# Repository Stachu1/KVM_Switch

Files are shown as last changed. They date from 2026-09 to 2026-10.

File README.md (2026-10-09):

# KVM Switch

A two-computer HDMI + USB KVM switch designed in KiCad.

This is a personal project with the goal of learning more about digital high-speed PCB design: controlled-impedance differential pairs, length matching, layer stackup and keeping signal integrity in check on HDMI and USB lines.

## PCB

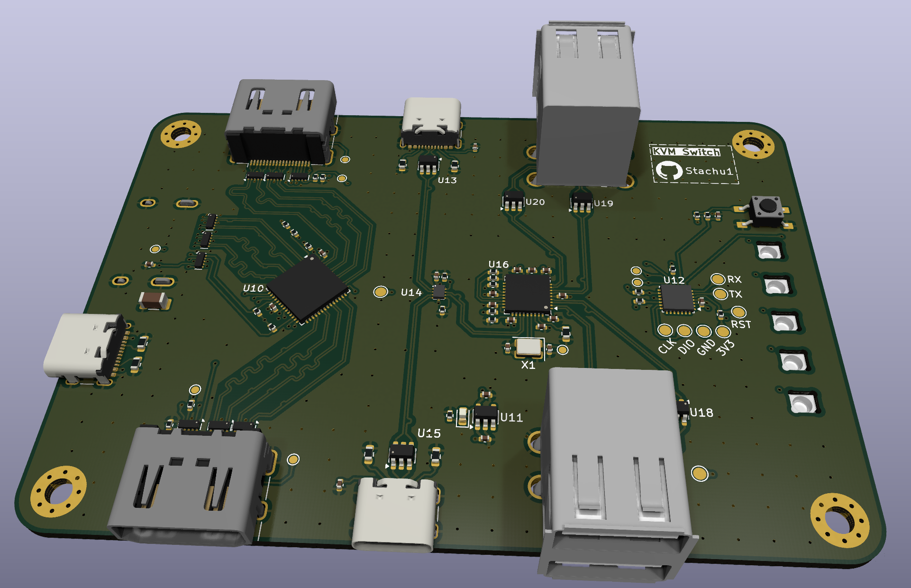
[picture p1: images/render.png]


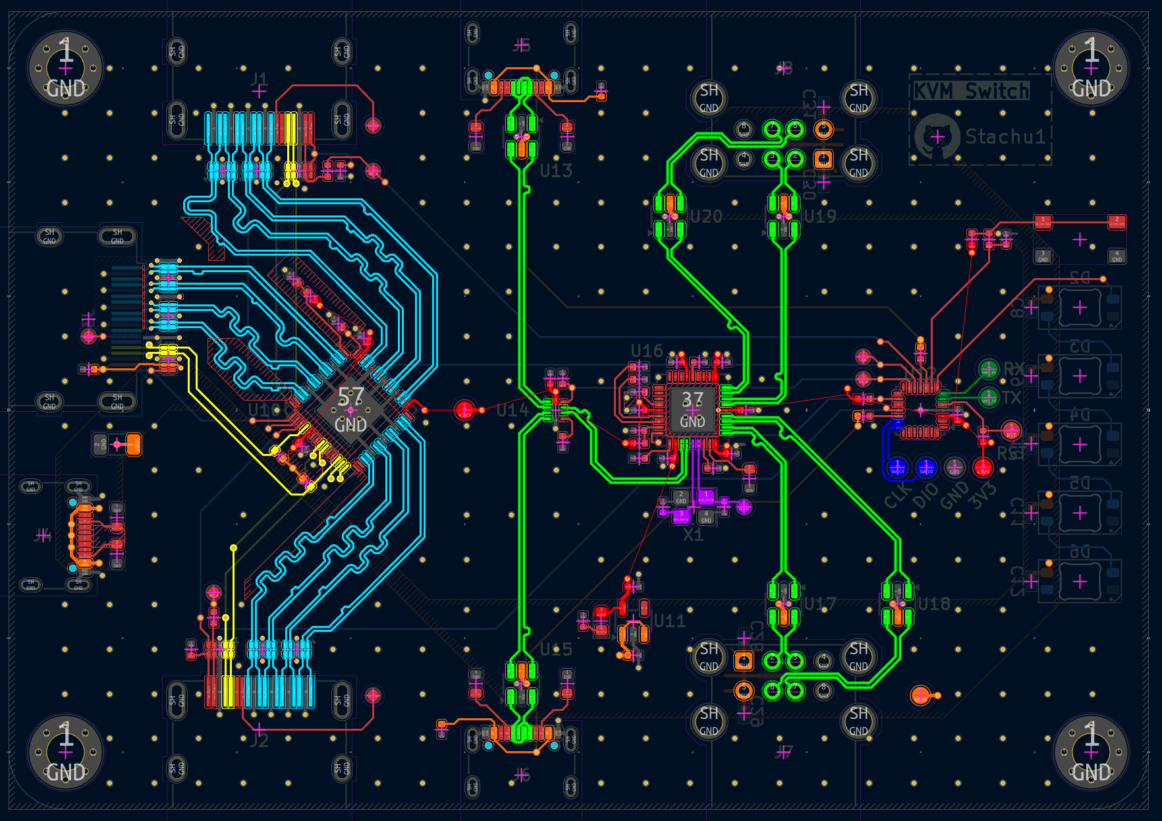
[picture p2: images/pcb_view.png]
KiCad PCB view


## Assembled device

Assembled device

## Overview

- Switches one HDMI display between two HDMI sources (TI HD3SS215)
- Shares USB peripherals between two hosts through a USB 2.0 hub (Microchip USB2514B) and a USB host selector (TI TS3USB221A)
- Two USB-C upstream ports for the hosts, stacked USB-A ports for peripherals
- STM32C031 microcontroller handles input selection via a push button, with an RGB status LED
- ESD protection on all external HDMI and USB connectors
- Powered over USB-C
- 4-layer PCB

## Repository layout

```
hardware/   KiCad project (schematics, PCB, custom library, BOM)
firmware/   Firmware for the STM32 (work in progress)
images/     Pictures used in this README
```

## Tools

- KiCad 10

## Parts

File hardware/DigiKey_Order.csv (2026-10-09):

Quantity | Part Number | Customer Reference
10 | 490-5869-1-ND | STL C1,C2
6 | 900-2086581001CT-ND | KVM J1,J2,J3
3 | 2073-USB4105-GF-ACT-ND | KVM J4,J5,J6 / STL J1
4 | 732-2107-ND | KVM J7,J8
20 | 296-43875-1-ND | KVM U1-U9
2 | 296-42335-1-ND | KVM U10
10 | 296-50411-1-ND | KVM U11 / STL U2
3 | 497-STM32C031G6U6-ND | KVM U12
2 | 497-17666-1-ND | STL U3
4 | 296-25222-1-ND | KVM U14
2 | USB2514BT/M2CT-ND | KVM U16
2 | SER3634CT-ND | KVM X1
2 | 50-ECS-80-18-33-JGN-CT-ND | STL X1

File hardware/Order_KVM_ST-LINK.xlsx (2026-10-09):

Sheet: Settings
KVM Switch + ST-LINK - combined DigiKey order
Prices: digikey.dk cut tape, fetched 2026-10-09 (listed excl. VAT, VAT added here). Quantities: KiCad BOM export of both schematics (DNP / test points excluded).
Input | Value | Note
KVM Switch boards to build | 2 | Drives the DigiKey Order sheet. Compare options on the Scenarios sheet.
ST-LINK boards to build | 2 | Panel has 10 positions - populate as many as you like.
VAT rate | 25% | Danish VAT. Ordering privately, so all totals are shown incl. VAT.
Delivery charge | 185.00 kr | digikey.dk: 'A delivery charge of kr. 185 will be billed on all orders less than kr. 550.'
Free delivery from | 550.00 kr | digikey.dk: 'Free delivery to Denmark on orders of kr. 550 or more.'
DigiKey's 185 / 550 kr are | excl. VAT | DigiKey doesn't say. 'excl. VAT' is the safe assumption (= 687.50 kr incl. VAT); the checkout cart will confirm.
Order summary (board counts above, incl. VAT)
Parts incl. VAT | 696.60 kr
Order value as DigiKey measures it | 557.28 kr | excl. or incl. VAT per B10 - this is what is compared with the 550 kr
Delivery incl. VAT | 0.00 kr
TOTAL TO PAY incl. VAT | 696.60 kr
Missing to free delivery (incl. VAT) | 0.00 kr
Advice | Free delivery reached
Lines with 0 / low stock | 1 | Check 'Stock @ fetch' on the DigiKey Order sheet
How to use
- Yellow cells with blue text are inputs - everything else is calculated.
- Scenarios sheet: totals for every KVM / ST-LINK combination (board counts in its header are editable).
- Pick a combination, enter it in B5/B6 - the DigiKey Order sheet then shows exactly what to put in the cart.
- DigiKey Order: 'Owned' is subtracted from Needed, 'Order?' Y/N, 'Extra' adds spares (use it to top up to free delivery), 'Price override' replaces the looked-up price.
- 'Next break' shows the qty at the next price break and the line cost there - sometimes buying more is cheaper.
- AX Parts / Owned parts: what to pull from stock. Enter 'On hand' to see shortages.
Design notes
- Drop-in replacements chosen for parts out of stock at DigiKey on 2026-10-09 (schematic DigiKey fields still show the old PNs):
- U14 TS3USB221AQRSERQ1 (296-27719-1-ND, 0 stock) -> TS3USB221ERSER (296-25222-1-ND): same RSE 10-UQFN, pinout, S/OE truth table, VCC 2.3-3.6V; ESD-enhanced, not automotive.
- C25 100u: old PN was a 1210 part on a C_1206 footprint and 0 stock -> GRM31CR61A107MEA8L, 100u 10V X5R 1206 (fits the footprint). C25 is on VBUS (5V).
- 5.1k 0603 RC0603FR-075K1L (0 stock) -> Stackpole RMCF0603FT5K10, same value/size/tolerance.
- USBLC6-2SC6: both old PNs (Slkormicro 0 stock, UMW) -> genuine ST USBLC6-2SC6 (497-5235-1-ND) for both boards.
- R3,R4 (47k, HDMI_OUT DDC SCL/SDA pull-ups to VBUS): likely not needed (sink/source pulls DDC up) - Order?=N, leave unpopulated.
- Owned HT7333 (SOT-23-3L) can't replace TLV75533 (U11 / ST-LINK U2): footprint is SOT-23-5, no pad for the 3rd pin. Keep ordering TLV75533.
- STM32F103C8T6TR: only 14 in stock at fetch time - check before ordering.
- ST-LINK J2: 732-5317-ND is a vertical THT header (61300411121), footprint is 'conn_01x04_P2.54_right_smd' - confirm.

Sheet: Scenarios
What does each build option cost? (DKK incl. VAT, delivery rules from Settings)
Uses Order?, Extra and Price override from the DigiKey Order sheet; only the board counts change. Edit the yellow board counts to try other combinations.
KVM boards |  | 1 | 1 | 1 | 1 | 2 | 2 | 2 | 2
ST-LINK boards |  | 2 | 3 | 4 | 5 | 2 | 3 | 4 | 5
DigiKey PN | Description | Line incl. VAT | Line incl. VAT | Line incl. VAT | Line incl. VAT | Line incl. VAT | Line incl. VAT | Line incl. VAT | Line incl. VAT
490-GRM31CR61A107MEA8LCT-ND | CAP CER 100UF 10V X5R 1206 | 0.00 kr | 0.00 kr | 0.00 kr | 0.00 kr | 0.00 kr | 0.00 kr | 0.00 kr | 0.00 kr
490-5869-1-ND | CAP CER 27PF 50V C0G 0402 | 1.73 kr | 2.07 kr | 2.42 kr | 2.76 kr | 1.73 kr | 2.07 kr | 2.42 kr | 2.76 kr
RMCF0603FT5K10CT-ND | RES 5.1K OHM 1% 1/10W 0603 | 0.00 kr | 0.00 kr | 0.00 kr | 0.00 kr | 0.00 kr | 0.00 kr | 0.00 kr | 0.00 kr
475-LGQ976.01-MGNI-35-1CT-ND | LED GREEN CLEAR 0603 SMD | 0.00 kr | 0.00 kr | 0.00 kr | 0.00 kr | 0.00 kr | 0.00 kr | 0.00 kr | 0.00 kr
475-LOQ976.01-P2R2-25-1-20-R18CT-ND | LED ORANGE CLEAR 0603 SMD | 0.00 kr | 0.00 kr | 0.00 kr | 0.00 kr | 0.00 kr | 0.00 kr | 0.00 kr | 0.00 kr
900-2086581001CT-ND | CONN RCPT HDMI V2.1 19POS SMD RA | 70.99 kr | 70.99 kr | 70.99 kr | 70.99 kr | 141.97 kr | 141.97 kr | 141.97 kr | 141.97 kr
2073-USB4105-GF-ACT-ND | CONN RCP USB2.0 TYPE-C 16P SMD RA | 13.10 kr | 13.10 kr | 13.10 kr | 19.65 kr | 19.65 kr | 26.20 kr | 32.75 kr | 39.30 kr
732-2107-ND | CONN RCPT USB2.0 TYPE-A STACKED R/A | 32.75 kr | 32.75 kr | 32.75 kr | 32.75 kr | 65.50 kr | 65.50 kr | 65.50 kr | 65.50 kr
732-5317-ND | CONN HEADER VERT 4POS 2.54MM | 0.00 kr | 0.00 kr | 0.00 kr | 0.00 kr | 0.00 kr | 0.00 kr | 0.00 kr | 0.00 kr
296-43875-1-ND | TVS DIODE 3.6VWM 8.8VC 10USON | 62.51 kr | 62.51 kr | 62.51 kr | 62.51 kr | 113.65 kr | 113.65 kr | 113.65 kr | 113.65 kr
296-42335-1-ND | IC DISPLAYPORT 2:1 DIFF SW 56QFN | 38.40 kr | 38.40 kr | 38.40 kr | 38.40 kr | 76.80 kr | 76.80 kr | 76.80 kr | 76.80 kr
296-50411-1-ND | IC REG LINEAR 3.3V 500MA SOT23-5 | 30.94 kr | 23.99 kr | 26.39 kr | 28.78 kr | 23.99 kr | 26.39 kr | 28.78 kr | 31.18 kr
497-STM32C031G6U6-ND | IC MCU 32BIT 32KB FLASH 28UFQFPN | 22.93 kr | 22.93 kr | 22.93 kr | 22.93 kr | 34.39 kr | 34.39 kr | 34.39 kr | 34.39 kr
497-17666-1-ND | IC MCU 32BIT 64KB FLASH 48LQFP | 119.55 kr | 179.33 kr | 239.10 kr | 298.88 kr | 119.55 kr | 179.33 kr | 239.10 kr | 298.88 kr
497-5235-1-ND | TVS DIODE 5V SOT23-6 (USB ESD) | 0.00 kr | 0.00 kr | 0.00 kr | 0.00 kr | 0.00 kr | 0.00 kr | 0.00 kr | 0.00 kr
296-25222-1-ND | IC USB SWITCH DUAL 1X2 10UQFN | 26.77 kr | 26.77 kr | 26.77 kr | 26.77 kr | 35.70 kr | 35.70 kr | 35.70 kr | 35.70 kr
USB2514BT/M2CT-ND | IC HUB CTLR 4PORT USB 2.0 HS 36SQFN | 20.30 kr | 20.30 kr | 20.30 kr | 20.30 kr | 40.60 kr | 40.60 kr | 40.60 kr | 40.60 kr
SER3634CT-ND | CRYSTAL 24.0000MHZ 9PF SMD | 6.71 kr | 6.71 kr | 6.71 kr | 6.71 kr | 13.43 kr | 13.43 kr | 13.43 kr | 13.43 kr
50-ECS-80-18-33-JGN-CT-ND | CRYSTAL 8.0000MHZ 18PF SMD | 9.65 kr | 14.47 kr | 19.30 kr | 24.12 kr | 9.65 kr | 14.47 kr | 19.30 kr | 24.12 kr
311-47.0KLRCT-ND | RES 47K OHM 1% 1/16W 0402 | 0.00 kr | 0.00 kr | 0.00 kr | 0.00 kr | 0.00 kr | 0.00 kr | 0.00 kr | 0.00 kr
Parts incl. VAT |  | 456.32 kr | 514.31 kr | 581.66 kr | 655.55 kr | 696.60 kr | 770.49 kr | 844.39 kr | 918.28 kr
Order value as DigiKey measures it |  | 365.06 kr | 411.45 kr | 465.33 kr | 524.44 kr | 557.28 kr | 616.40 kr | 675.51 kr | 734.62 kr
Delivery incl. VAT |  | 231.25 kr | 231.25 kr | 231.25 kr | 231.25 kr | 0.00 kr | 0.00 kr | 0.00 kr | 0.00 kr
TOTAL TO PAY incl. VAT |  | 687.57 kr | 745.56 kr | 812.91 kr | 886.80 kr | 696.60 kr | 770.49 kr | 844.39 kr | 918.28 kr
Missing to free delivery (incl. VAT) |  | 231.18 kr | 173.19 kr | 105.84 kr | 31.95 kr | 0.00 kr | 0.00 kr | 0.00 kr | 0.00 kr
Top up or pay delivery? |  | Top up | Top up | Top up | Top up | Free | Free | Free | Free
Total if topped up to free delivery |  | 687.50 kr | 687.50 kr | 687.50 kr | 687.50 kr | 696.60 kr | 770.49 kr | 844.39 kr | 918.28 kr
- 'Top up' = the amount missing to free delivery is less than the delivery charge, so extra parts (spares / Extra column) cost less than shipping.
- Break-even: with 550/185 excl. VAT, topping up pays off once parts exceed 365 kr excl. VAT (456.25 kr incl. VAT).
- 'Total if topped up' = what you pay if you add parts up to exactly the free-delivery threshold.

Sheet: DigiKey Order
DigiKey order - KVM Switch + ST-LINK (board counts from Settings)
 |  |  |  |  |  |  |  |  |  |  |  |  |  |  |  |  |  |  | DigiKey price breaks (DKK excl. VAT, as listed on digikey.dk) - edit if prices change
DigiKey PN | Manufacturer | MPN | Description | KVM refs | KVM qty/board | ST-LINK refs | ST-LINK qty/board | Stock @ fetch | Needed | Owned | Order? | Extra | Order qty | Unit price excl. VAT (auto) | Price override (excl. VAT) | Unit price incl. VAT | Line total incl. VAT | Next break: qty / line incl. VAT | Break qty 1 | Break qty 2 | Break qty 3 | Break qty 4 | Break qty 5 | Break qty 6 | Break qty 7 | Break qty 8 | Price 1 excl. VAT | Price 2 excl. VAT | Price 3 excl. VAT | Price 4 excl. VAT | Price 5 excl. VAT | Price 6 excl. VAT | Price 7 excl. VAT | Price 8 excl. VAT
490-GRM31CR61A107MEA8LCT-ND | Murata | GRM31CR61A107MEA8L | CAP CER 100UF 10V X5R 1206 | C25 | 1 |  | 0 | 478,277 | 2 | 0 | N | 0 | 0 | 3.60000 kr |  | 4.50000 kr | 0.00 kr |  | 1 | 10 | 50 | 100 | 500 |  |  |  | 3.60000 kr | 2.18800 kr | 1.63100 kr | 1.46130 kr | 1.17454 kr
490-5869-1-ND | Murata | GRM1555C1H270JA01D | CAP CER 27PF 50V C0G 0402 |  | 0 | C1,C2 | 2 | 4,482,233 | 4 | 0 | Y | 6 | 10 | 0.13800 kr |  | 0.17250 kr | 1.73 kr | 50 pcs = 5.74 kr | 1 | 10 | 50 | 100 | 500 |  |  |  | 0.66000 kr | 0.13800 kr | 0.09180 kr | 0.07790 kr | 0.05398 kr
RMCF0603FT5K10CT-ND | Stackpole | RMCF0603FT5K10 | RES 5.1K OHM 1% 1/10W 0603 | R10,R12,R17,R18,R22,R23 | 6 | R3,R4 | 2 | 145,188 | 16 | 0 | N | 0 | 0 | 0.66000 kr |  | 0.82500 kr | 0.00 kr |  | 1 | 10 | 25 | 50 | 100 | 250 | 500 | 1000 | 0.66000 kr | 0.13800 kr | 0.09960 kr | 0.07860 kr | 0.06290 kr | 0.04820 kr | 0.03982 kr | 0.03334 kr
475-LGQ976.01-MGNI-35-1CT-ND | ams OSRAM | LG Q976.01-MGNI-35-1 | LED GREEN CLEAR 0603 SMD | D1 | 1 | D1 | 1 | 1,110 | 4 | 0 | N | 0 | 0 | 0.92000 kr |  | 1.15000 kr | 0.00 kr |  | 1 | 10 | 100 | 500 | 1000 | 2000 |  |  | 0.92000 kr | 0.60900 kr | 0.42120 kr | 0.33274 kr | 0.30327 kr | 0.27802 kr
475-LOQ976.01-P2R2-25-1-20-R18CT-ND | ams OSRAM | LO Q976.01-P2R2-25-1-20-R18 | LED ORANGE CLEAR 0603 SMD |  | 0 | D2 | 1 | 126,647 | 2 | 0 | N | 0 | 0 | 0.92000 kr |  | 1.15000 kr | 0.00 kr |  | 1 | 10 | 100 | 500 | 1000 | 2000 |  |  | 0.92000 kr | 0.60900 kr | 0.42120 kr | 0.33274 kr | 0.30327 kr | 0.27802 kr
900-2086581001CT-ND | Molex | 2086581001 | CONN RCPT HDMI V2.1 19POS SMD RA | J1,J2,J3 | 3 |  | 0 | 22,147 | 6 | 0 | Y | 0 | 6 | 18.93000 kr |  | 23.66250 kr | 141.98 kr | 10 pcs = 200.84 kr | 1 | 10 | 25 | 50 | 100 |  |  |  | 18.93000 kr | 16.06700 kr | 15.05960 kr | 14.33920 kr | 13.65410 kr
2073-USB4105-GF-ACT-ND | GCT | USB4105-GF-A | CONN RCP USB2.0 TYPE-C 16P SMD RA | J4,J5,J6 | 3 | J1 | 1 | 103,534 | 8 | 7 | Y | 2 | 3 | 5.24000 kr |  | 6.55000 kr | 19.65 kr | 10 pcs = 55.35 kr | 1 | 10 | 25 | 50 | 100 | 250 |  |  | 5.24000 kr | 4.42800 kr | 4.15000 kr | 3.95220 kr | 3.76300 kr | 3.52704 kr
732-2107-ND | Wurth Elektronik | 61400826021 | CONN RCPT USB2.0 TYPE-A STACKED R/A | J7,J8 | 2 |  | 0 | 15,423 | 4 | 0 | Y | 0 | 4 | 13.10000 kr |  | 16.37500 kr | 65.50 kr | 10 pcs = 144.84 kr | 1 | 10 | 50 | 100 |  |  |  |  | 13.10000 kr | 11.58700 kr | 10.92020 kr | 10.30450 kr
732-5317-ND | Wurth Elektronik | 61300411121 | CONN HEADER VERT 4POS 2.54MM |  | 0 | J2 | 1 | 132,393 | 2 | 0 | N | 0 | 0 | 1.18000 kr |  | 1.47500 kr | 0.00 kr |  | 1 | 10 | 25 | 50 | 100 |  |  |  | 1.18000 kr | 1.01500 kr | 0.84120 kr | 0.70340 kr | 0.68580 kr
296-43875-1-ND | Texas Instruments | TPD4E02B04DQAR | TVS DIODE 3.6VWM 8.8VC 10USON | U1-U9 | 9 |  | 0 | 1,336 | 18 | 0 | Y | 2 | 20 | 4.54600 kr |  | 5.68250 kr | 113.65 kr | 50 pcs = 209.76 kr | 1 | 10 | 50 | 100 | 500 |  |  |  | 7.27000 kr | 4.54600 kr | 3.35620 kr | 2.97040 kr | 2.29198 kr
296-42335-1-ND | Texas Instruments | HD3SS215RTQR | IC DISPLAYPORT 2:1 DIFF SW 56QFN | U10 | 1 |  | 0 | 2,402 | 2 | 0 | Y | 0 | 2 | 30.72000 kr |  | 38.40000 kr | 76.80 kr | 10 pcs = 291.80 kr | 1 | 10 | 25 | 100 | 250 |  |  |  | 30.72000 kr | 23.34400 kr | 21.49440 kr | 19.46140 kr | 18.49984 kr
296-50411-1-ND | Texas Instruments | TLV75533PDBVR | IC REG LINEAR 3.3V 500MA SOT23-5 | U11 | 1 | U2 | 1 | in stock | 4 | 0 | Y | 6 | 10 | 1.91900 kr |  | 2.39875 kr | 23.99 kr | 25 pcs = 53.46 kr | 1 | 10 | 25 | 100 | 250 | 500 | 1000 |  | 2.75000 kr | 1.91900 kr | 1.71080 kr | 1.48030 kr | 1.37052 kr | 1.30436 kr | 1.24974 kr
497-STM32C031G6U6-ND | STMicroelectronics | STM32C031G6U6 | IC MCU 32BIT 32KB FLASH 28UFQFPN | U12 | 1 |  | 0 | 3,703 | 2 | 0 | Y | 1 | 3 | 9.17000 kr |  | 11.46250 kr | 34.39 kr | 10 pcs = 83.26 kr | 1 | 10 | 50 | 100 | 490 | 980 |  |  | 9.17000 kr | 6.66100 kr | 5.64340 kr | 5.32970 kr | 4.80235 kr | 4.63660 kr
497-17666-1-ND | STMicroelectronics | STM32F103C8T6TR | IC MCU 32BIT 64KB FLASH 48LQFP |  | 0 | U3 | 1 | 14 | 2 | 0 | Y | 0 | 2 | 47.82000 kr |  | 59.77500 kr | 119.55 kr | 10 pcs = 459.40 kr | 1 | 10 | 50 | 100 | 500 |  |  |  | 47.82000 kr | 36.75200 kr | 32.30980 kr | 30.93370 kr | 28.60542 kr
497-5235-1-ND | STMicroelectronics | USBLC6-2SC6 | TVS DIODE 5V SOT23-6 (USB ESD) | U13,U15,U17-U20 | 6 | U1 | 1 | 132,634 | 14 | 17 | Y | 0 | 0 | 3.54000 kr |  | 4.42500 kr | 0.00 kr |  | 1 | 10 | 50 | 100 | 500 |  |  |  | 3.54000 kr | 2.15500 kr | 1.56160 kr | 1.36760 kr | 1.02586 kr
296-25222-1-ND | Texas Instruments | TS3USB221ERSER | IC USB SWITCH DUAL 1X2 10UQFN | U14 | 1 |  | 0 | 21,915 | 2 | 0 | Y | 2 | 4 | 7.14000 kr |  | 8.92500 kr | 35.70 kr | 10 pcs = 64.35 kr | 1 | 10 | 25 | 100 | 250 | 500 | 1000 |  | 7.14000 kr | 5.14800 kr | 4.64800 kr | 4.09900 kr | 3.83724 kr | 3.67966 kr | 3.58770 kr
USB2514BT/M2CT-ND | Microchip | USB2514BT/M2 | IC HUB CTLR 4PORT USB 2.0 HS 36SQFN | U16 | 1 |  | 0 | 19,915 | 2 | 0 | Y | 0 | 2 | 16.24000 kr |  | 20.30000 kr | 40.60 kr | 25 pcs = 501.08 kr | 1 | 25 |  |  |  |  |  |  | 16.24000 kr | 16.03440 kr
SER3634CT-ND | EPSON | TSX-3225 24.0000MF20G-AC3 | CRYSTAL 24.0000MHZ 9PF SMD | X1 | 1 |  | 0 | 100,414 | 2 | 0 | Y | 0 | 2 | 5.37000 kr |  | 6.71250 kr | 13.43 kr | 10 pcs = 58.46 kr | 1 | 10 | 25 | 50 | 100 |  |  |  | 5.37000 kr | 4.67700 kr | 4.42000 kr | 4.23780 kr | 4.06230 kr
50-ECS-80-18-33-JGN-CT-ND | ECS Inc. | ECS-80-18-33-JGN-TR | CRYSTAL 8.0000MHZ 18PF SMD |  | 0 | X1 | 1 | 35,744 | 2 | 0 | Y | 0 | 2 | 3.86000 kr |  | 4.82500 kr | 9.65 kr | 10 pcs = 41.84 kr | 1 | 10 | 25 | 50 | 100 | 250 | 500 |  | 3.86000 kr | 3.34700 kr | 3.16760 kr | 3.03780 kr | 2.91150 kr | 2.75364 kr | 2.63952 kr
311-47.0KLRCT-ND | YAGEO | RC0402FR-0747KL | RES 47K OHM 1% 1/16W 0402 | R3,R4 | 2 |  | 0 | 1,680,645 | 4 | 0 | N | 0 | 0 | 0.66000 kr |  | 0.82500 kr | 0.00 kr |  | 1 | 10 | 25 | 50 | 100 | 250 | 500 | 1000 | 0.66000 kr | 0.13800 kr | 0.09960 kr | 0.07860 kr | 0.06350 kr | 0.04848 kr | 0.04008 kr | 0.03354 kr
 |  |  |  |  |  |  |  |  |  |  |  |  |  |  |  | Parts total incl. VAT | 696.60 kr

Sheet: AX Parts
AX parts - not ordered, pull from stock
AX # | Value | Package | KVM refs | KVM qty/board | ST-LINK refs | ST-LINK qty/board | Total needed | On hand | Short
27730 | 1u | C 0402 | C1-C18,C21-C24,C28-C31 | 26 | C4,C6-C10 | 6 | 64
27705 | 10p | C 0402 | C19,C20 | 2 |  | 0 | 4
27726 | 100n | C 0402 | C26,C27 | 2 |  | 0 | 4
27204 | 10u | C 0603 |  | 0 | C3,C5 | 2 | 4
201002 | 10k | R 0402 | R1,R2,R6-R8,R13-R16,R19-R21,R24,R25 | 14 | R1,R2,R5-R9 | 7 | 42
201003 | 100k | R 0402 | R5,R9,R27-R30 | 6 |  | 0 | 12
204700 | 470 | R 0402 | R11 | 1 | R10,R13 | 2 | 6
202209 | 22 | R 0402 |  | 0 | R11,R12,R15-R17 | 5 | 10
201000 | 100 | R 0402 |  | 0 | R14 | 1 | 2
201001 | 1k | R 0402 |  | 0 | R18 | 1 | 2
141202 | 12k | R 0603 | R26 | 1 |  | 0 | 2
Total needed uses the board counts on the Settings sheet.

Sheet: Owned parts
Already owned - not ordered
Part # | Value | Package | KVM refs | KVM qty/board | ST-LINK refs | ST-LINK qty/board | Total needed | On hand | Short
LCSC C5149201 | SK6812MINI-E | 3.2x2.8 reverse-mount | D2-D6 | 5 |  | 0 | 10
LCSC C780491 | SPST-NO | UK-B0206-G5-250-JZ | SW1 | 1 |  | 0 | 2
RMCF0603FT5K10 | 5.1k | R 0603 | R10,R12,R17,R18,R22,R23 | 6 | R3,R4 | 2 | 16
GRM31CR61A107MEA8L | 100u 10V | C 1206 | C25 | 1 |  | 0 | 2
LG Q976.01 (green) | GLED | LED 0603 | D1 | 1 | D1 | 1 | 4
LO Q976.01 (orange) | OLED | LED 0603 |  | 0 | D2 | 1 | 2
61300411121 | Pin header 1x4 | 2.54mm |  | 0 | J2 | 1 | 2
USB4105-GF-A (own 7) | USB-C 16P | SMD RA | J4-J6 | 3 | J1 | 1 | 8 | 7 | 1
USBLC6-2SC6 (own 17) | USB ESD | SOT-23-6 | U13,U15,U17-U20 | 6 | U1 | 1 | 14 | 17 | 0
Total needed uses the board counts on the Settings sheet.
Partly owned lines (USB-C, USBLC6): the DigiKey Order sheet orders only Needed minus Owned.

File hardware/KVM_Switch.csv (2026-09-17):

Reference | Qty | Value | DigiKey | AX | LCSC
C1,C2,C3,C4,C5,C6,C7,C8,C9,C10,C11,C12,C13,C14,C15,C16,C17,C18,C21,C22,C23,C24,C28,C29,C30,C31 | 26 | 1u |  | 27730
C19,C20 | 2 | 10p |  | 27705
C25 | 1 | 100u | 490-9969-1-ND
C26,C27 | 2 | 100n |  | 27726
D1 | 1 | GLED | 475-LGQ976.01-MGNI-35-1CT-ND
D2,D3,D4,D5,D6 | 5 | SK6812MINI-E |  |  | C5149201
J1,J2,J3 | 3 | HDMI_A | 900-2086581001CT-ND
J4,J5,J6 | 3 | USB_C_Receptacle_USB2.0_16P | 2073-USB4105-GF-ACT-ND
J7,J8 | 2 | USB_A_Stacked | 732-2107-ND
R1,R2,R6,R7,R8,R13,R14,R15,R16,R19,R20,R21,R24,R25 | 14 | 10k |  | 201002
R3,R4 | 2 | 47k
R5,R9,R27,R28,R29,R30 | 6 | 100k |  | 201003
R10,R12,R17,R18,R22,R23 | 6 | 5.1k | 311-5.10KHRCT-ND
R11 | 1 | 470 |  | 204700
R26 | 1 | 12k |  | 141202
SW1 | 1 | SPST-NO |  |  | C780491
U1,U2,U3,U4,U5,U6,U7,U8,U9 | 9 | TPD4E02B04DQA | 296-43875-1-ND
U10 | 1 | HD3SS215RTQR | 296-42335-1-ND
U11 | 1 | TLV75533PDBV | 296-50411-1-ND
U12 | 1 | STM32C031G6Ux | 497-STM32C031G6U6-ND
U13,U15,U17,U18,U19,U20 | 6 | USBLC6-2SC6 | 5399-USBLC6-2SC6CT-ND
U14 | 1 | TS3USB221AQRSERQ1 | 296-27719-1-ND
U16 | 1 | USB2514B_Bi | USB2514BT/M2CT-ND
X1 | 1 | 24MHz | SER3634CT-ND

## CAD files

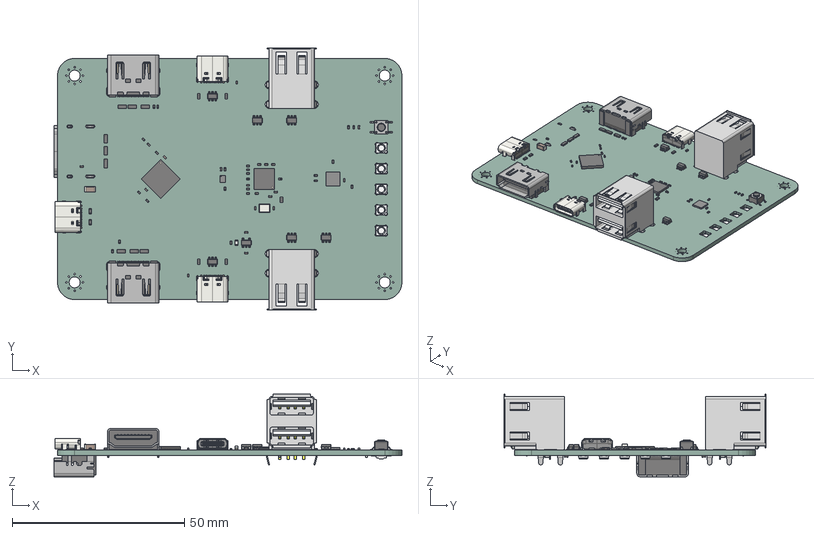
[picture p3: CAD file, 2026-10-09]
hardware/KVM_Switch.step
101.0 x 76.1 x 24.0 mm
C_0402_1005Metric x 30
R_0402_1005Metric x 23
SOT-23-6 x 6
USB_C_Receptacle_16P_TopMnt_Horizontal_GCT_USB4105-xx-A x 3
R_0603_1608Metric x 7
SW_Push_1P1T_NO_E-Switch_TL3301NxxxxxG
TS5A23157RSER
SOT-23-5
USON_10_25x10mm_Pitch05mm x 9
QFN_56_1EP_8x8mm_Pitch05mm_EP52x45mm
HDMI_A_Molex_208658-1001_Horizontal x 3
USB-A-D-TH_S x 2
USB-A-D-W-TH_B x 2
USB-A-D-TH_P x 2
Crystal_SMD_3225-4Pin_3.2x2.5mm
STM32F031G6U6
QFN-36-1EP_6x6mm_Pitch0.5mm
LED_0603_1608Metric
C_1206_3216Metric
Pin1 x 5
Pin2 x 5
Pin3 x 5
Pin4 x 5
KVMDCEA_PCB

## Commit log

2026-08-24 Create KiCad project
    [KVM_Switch.kicad_pcb, KVM_Switch.kicad_sch]
2026-08-24 Added switching ICs and MCU
    [KVM_Switch.kicad_pcb, KVM_Switch.kicad_sch]
2026-08-25 USB-C connectors
    [KVM_Switch.kicad_sch]
2026-08-25 Moved stuff armound & added components
    [HDMI_Conn.kicad_sch, HDMI_Switch.kicad_sch, KVM_Switch.kicad_pcb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]
2026-08-27 Better schematics structure & Hub sub-circuit connections
    [KVM_Switch.kicad_sch, MCU.kicad_sch, Power.kicad_sch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]
2026-09-01 Updated symbols' DigiKey part no.
    [HDMI_Conn.kicad_sch, HDMI_Switch.kicad_sch, USB_A_Conn.kicad_sch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]
2026-09-04 Changed MCU & Stared routing HDMI connectiors
    [HDMI_Conn.kicad_sch, HDMI_Switch.kicad_sch, KVM_Switch.kicad_sch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]
2026-09-04 HDMI schematics
    [HDMI_IN.kicad_sch, HDMI_OUT.kicad_sch, HDMI_Switch.kicad_sch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]
2026-09-06 Schematics done
    [HDMI_IN.kicad_sch, HDMI_OUT.kicad_sch, HDMI_Switch.kicad_sch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]
2026-09-06 Fixed DRC & Adnotations
    [HDMI_IN.kicad_sch, HDMI_OUT.kicad_sch, HDMI_Switch.kicad_sch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]
2026-09-06 Updated library structure
    [HDMI_Switch.kicad_sch, KVM_Switch.kicad_pcb, KVM_Switch.kicad_sch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]
2026-09-07 Library and Schematics Fixes
    [HDMI_Switch.kicad_sch, KVM_Switch.kicad_pcb, KVM_Switch.kicad_sch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]
2026-09-07 More schematics fixes & Layout attempt
    [HDMI_IN.kicad_sch, HDMI_OUT.kicad_sch, HDMI_Switch.kicad_sch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]
2026-09-07 New layout & set stackup
    [HDMI_IN.kicad_sch, KVM_Switch.kicad_pcb]
2026-09-08 Placed Connectors where i want them - I thnik
    [KVM_Switch.kicad_pcb, USB_A_Conn.kicad_sch]
2026-09-08 Routed HDMI TMDS
    [KVM_Switch.kicad_pcb]
2026-09-09 TMDS length matching *not done
    [KVM_Switch.kicad_pcb]
2026-09-10 TMDS tunned to length
    [KVM_Switch.kicad_pcb]
2026-09-10 Routed USB
    [KVM_Switch.kicad_pcb]
2026-09-10 USB matched lenght
    [KVM_Switch.kicad_pcb]
2026-09-10 Routed some low-speed tracks
    [KVM_Switch.kicad_pcb]
2026-09-11 Added series resistors for USB_DET & SW, HubOsc testpoints
    [HDMI_IN.kicad_sch, HDMI_Switch.kicad_sch, KVM_Switch.kicad_pcb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]
2026-09-11 VBUS and +3V3 zones routing
    [KVM_Switch.kicad_pcb, USB_A_Conn.kicad_sch]
2026-09-11 Fighting with DRC
    [KVM_Switch.kicad_pcb, MCU.kicad_sch]
2026-09-11 Added ESD protection for the remaining HDMI pins - Not routed yet
    [HDMI_IN.kicad_sch, HDMI_OUT.kicad_sch, HDMI_Switch.kicad_sch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]
2026-09-12 Routed remaining ESD protection
    [HDMI_IN.kicad_sch, HDMI_OUT.kicad_sch, KVM_Switch.kicad_pcb]
2026-09-15 Rerouted HDMI TMDS
    [KVM_Switch.kicad_pcb]
2026-09-16 i2c rerouted
    [KVM_Switch.kicad_pcb]
2026-09-17 Fix naming typo: KVM_Swtich -> KVM_Switch
    Renamed the footprint library folder library/KVM_Swtich.pretty to
    library/KVM_Switch.pretty and the 3D model swtich_smd_6x6mm.step to
    switch_smd_6x6mm.step, and updated every reference across
    fp-lib-table, sym-lib-table, the schematics, symbols.kicad_sym, and
    the PCB. Also fixed a stray "Swtich A to C" text label.
    [HDMI_Switch.kicad_sch, KVM_Switch.kicad_pcb, MCU.kicad_sch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]
2026-09-17 Updated custom rules & Changed switch
    [KVM_Switch.kicad_pcb, MCU.kicad_sch, USB_A_Conn.kicad_sch]
2026-09-17 USB fixes
    [KVM_Switch.kicad_pcb]
2026-09-17 Slikscreen cleanup
    [KVM_Switch.kicad_pcb, KVM_Switch_BOM.csv, MCU.kicad_sch]
2026-09-17 DRC fixes
    [KVM_Switch.kicad_pcb]
2026-10-08 Improved TMDS return current path
    [KVM_Switch.kicad_pcb]
2026-10-09 stitching vias
    [KVM_Switch.kicad_pcb]
2026-10-09 Schmatics -> PCB link update
    [KVM_Switch.kicad_pcb]
2026-10-09 Teardrops and fill zones
    [KVM_Switch.kicad_pcb]
2026-10-09 mfg export
    [KVM_Switch.csv, KVM_Switch.kicad_pcb, KVM_Switch.step]
2026-10-09 Silkscreen update
    [KVM_Switch.kicad_pcb]
2026-10-09 Moved PCB files to hardware dir
    [HDMI_IN.kicad_sch, HDMI_OUT.kicad_sch, HDMI_Switch.kicad_sch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]
2026-10-09 Added DigiKey_Okrder files
    [DigiKey_Order.csv, Order_KVM_ST-LINK.xlsx]
2026-10-20 Firmware: event-only LED animations, fix first-LED latch, docs
    - LEDs are dark at rest and only show events, each fading out on its own:
    a wave from the old to the new host on switch, a pulse at a host's end
    when it connects, and a flash when brightness changes.
    - Default colors: host A orange, host B purple. The settings record ID is
    bumped so boards with old saved colors pick up the new defaults.
    - Fix D2 staying dark with the pattern shifted one LED: the SPI MOSI line
    did not reliably idle low, so the first LED never saw the >80 us reset.
    PA2 is now a GPIO driven low between frames; each frame starts with a
    0x00 byte so handing the pin to the SPI happens on a low level.
    - Enab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
2026-10-20 added assembled images
2026-10-29 Added a 3D printed case
